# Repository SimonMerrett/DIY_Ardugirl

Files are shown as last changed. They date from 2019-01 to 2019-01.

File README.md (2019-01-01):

# DIY_Ardugirl
A SAMD21-based riff on the Arduboy handheld console. This is definitely Work in Progress and is not for production

The original has:
- ATmega32u4 processor 
- small OLED screen
- no additional storage
- speaker

This will have
- SAMD21G18A as it's processor
- larger daylight readable LCD screen, with dimmable backlight
- SPI flash and micro SD card slot (overkill - the latter may not be populated)
- headphone jack
- infrared rx/tx for possible multiplayer comms
- optional mini joystick

# Forum discussion
The Arduboy forum has [a thread](https://community.arduboy.com/t/wip-simon-merretts-arduboy-clone/6676) relevant to this design

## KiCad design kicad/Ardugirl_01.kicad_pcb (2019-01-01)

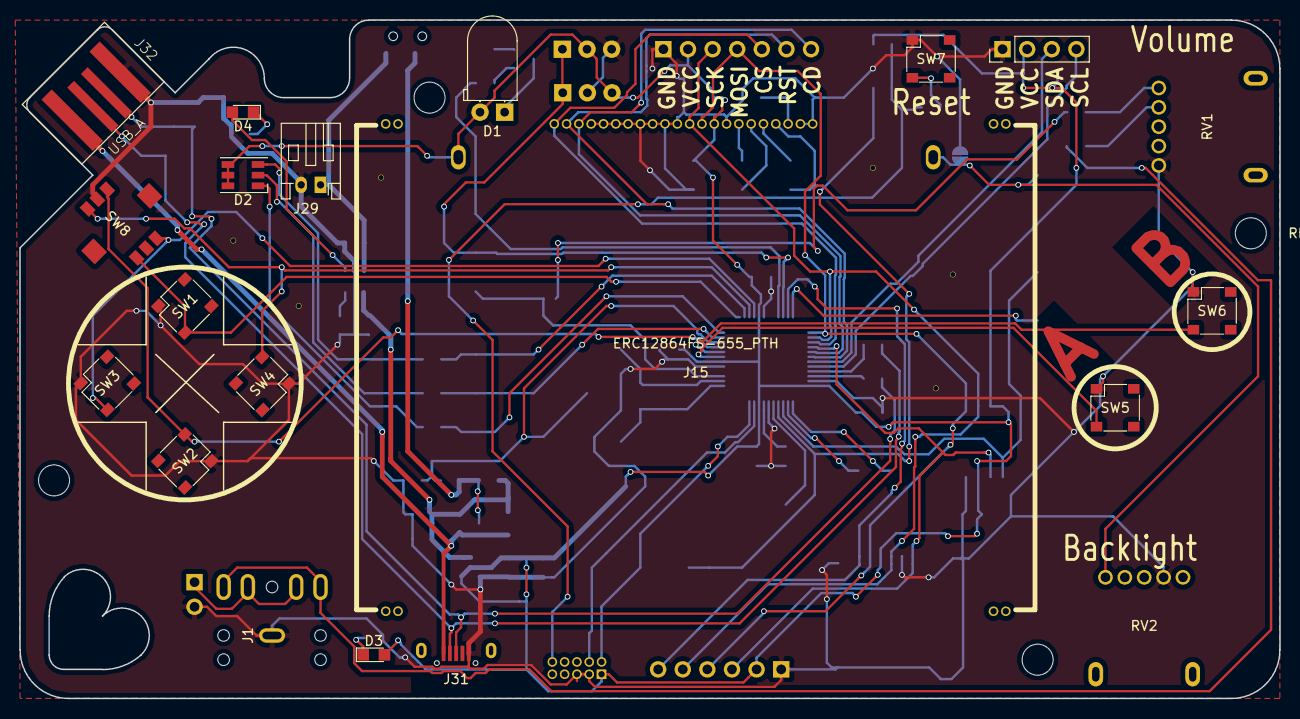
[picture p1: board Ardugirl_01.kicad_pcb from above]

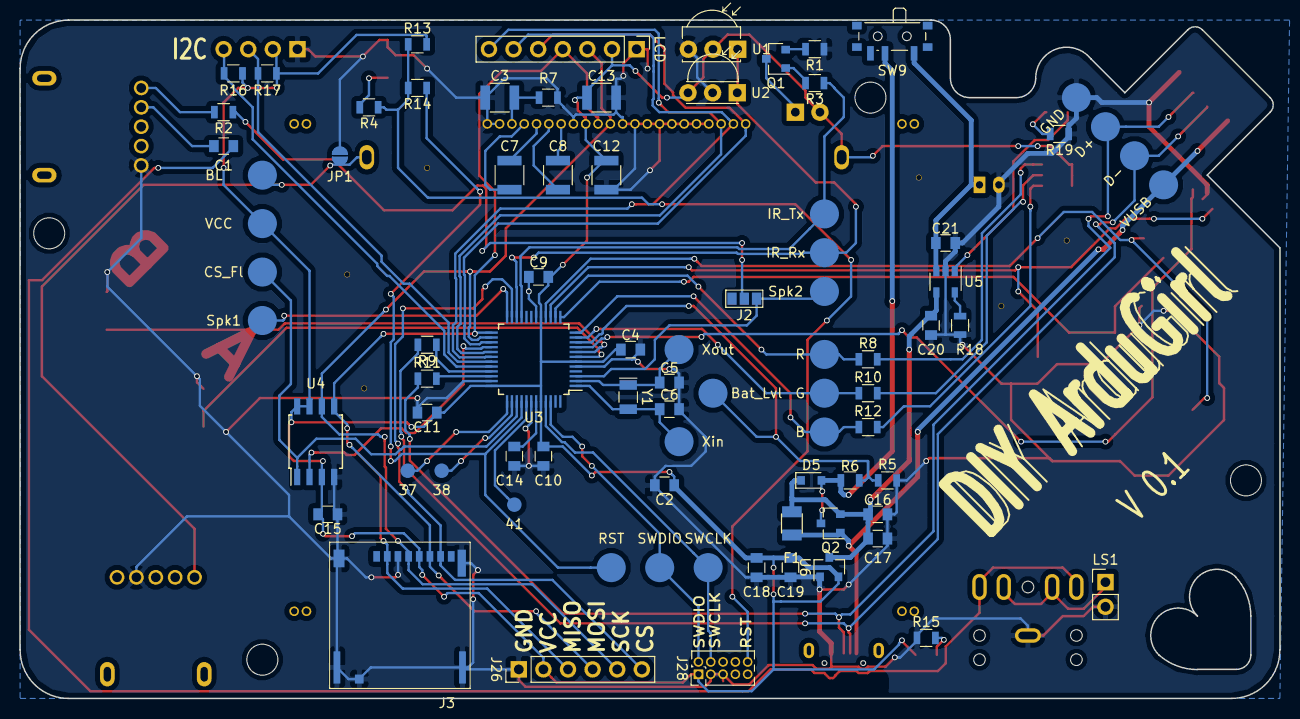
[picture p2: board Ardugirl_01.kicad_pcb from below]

Board: 2 copper layers, 130.0 x 70.0 mm, 102 parts (82 on the bottom side), 66 nets.

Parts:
37, 38: TP_Small; Measurement_Point_Round-SMD-Pad_Small
41: Measurement_Point_Round-SMD-Pad_Small
B: TEST; Measurement_Point_Round-SMD-Pad_Big
BL: K(-); Measurement_Point_Round-SMD-Pad_Big
Bat_Lvl: TEST; Measurement_Point_Round-SMD-Pad_Big
C1: 100u; C_0805
C2: 47u; C_0805
C3: 0.33u 25V; C_1210
C4, C9, C10, C11: 100n; C_0805
C5, C6: 12.5p; C_0805
C7, C8: 2.2u; C_1210
C12: 0.1u; C_1210
C13: 10u; C_1210
C14: C; C_0805
C15, C20, C21: 10u; C_0805
C16: Xu; C_0805
C17, C18: 1u; C_0805
C19: 0.1u; C_0805
CS_Fl: TEST; Measurement_Point_Round-SMD-Pad_Big
D1: IR_LED; LED_D5.0mm_Horizontal_O1.27mm_Z9.0mm
D2: LED_RGB; LED_RGB_PLCC-6
D3: PWR_LED; LED_0805
D4: LED; LED_0805
D5: D_Schottky; D_0805
D+: TEST; Measurement_Point_Round-SMD-Pad_Big
D-: TEST; Measurement_Point_Round-SMD-Pad_Big
F1: Polyfuse; Fuse_SMD1206_Reflow
G: TEST; Measurement_Point_Round-SMD-Pad_Big
GND: TEST_1P; Measurement_Point_Round-SMD-Pad_Big
I2C: I2C Header; Pin_Header_Straight_1x04_Pitch2.54mm
IR_Rx: TEST; Measurement_Point_Round-SMD-Pad_Big
IR_Tx: TEST; Measurement_Point_Round-SMD-Pad_Big
J1: JACK_TRS_5PINS; 3.5mm_Jack_5P
J2: GS3
J3: Micro_SD_Card; uSD_Molex
J15: CONN_01X24; ERC12864FS-655_PTH
J26: SD Header; Pin_Header_Straight_1x06_Pitch2.54mm
J28: SWD_02X05; Pin_Header_Straight_2x05_Pitch1.27mm
J29: CONN_BATT; JST_PH_S2B-PH-K_02x2.00mm_Angled
J31: USB_A; USB_micro-Korean_UF-M5DD-Y1
J32: USB_A; USB-A-PCB
JP1: Jumper_NO; JUMPER-SOLDER-SMD
LCD: LDC Header; Socket_Strip_Straight_1x07_Pitch2.54mm
LS1: Speaker; Pin_Header_Straight_1x02_Pitch2.54mm
Q1: Q_NMOS_GSD; SOT-23
Q2: Q_PMOS_GSD; SOT-23
R: TEST; Measurement_Point_Round-SMD-Pad_Big
R1: R; R_0805
R2: 270R; R_0805
R3, R9, R11: 22R; R_0805
R4: 47R; R_0805
R5, R6, R13, R16, R17: 10k; R_0805
R7: 10M; R_0805
R8, R10, R12, R15: 220R; R_0805
R14: 330R; R_0805
R18: 2k; R_0805
R19: 1k; R_0805
RST: TEST_1P; Measurement_Point_Round-SMD-Pad_Big
RV1: POT; Variable_R_PTH_5pin_14mm
RV2: 1k; Variable_R_PTH_5pin_14mm
SW1: UP; SW_Tactile_SMD_4.8_4.8
SW2: DOWN; SW_Tactile_SMD_4.8_4.8
SW3: LEFT; SW_Tactile_SMD_4.8_4.8
SW4: RIGHT; SW_Tactile_SMD_4.8_4.8
SW5: Button_A; SW_Tactile_SMD_4.8_4.8
SW6: Button_B; SW_Tactile_SMD_4.8_4.8
SW7: Reset; SW_Tactile_SMD_4.8_4.8
SW8: Joystick_5W; Joystick_5W_SKRH
SW9: SW_SPDT; SW_SPDT_PCM12
SWCLK: TEST; Measurement_Point_Round-SMD-Pad_Big
SWDIO: TEST; Measurement_Point_Round-SMD-Pad_Big
Spk1, Spk2: TEST; Measurement_Point_Round-SMD-Pad_Big
U1: TSOP325xx; IRReceiver_Vishay_MOLD-3pin
U2: TSOP335xx; IRReceiver_Vishay_MINIMOLD-3pin
U3: SAMD21G18A-MU; TQFP-48_7x7mm_Pitch0.5mm
U4: SST25PF040C; SOIJ-8_5.3x5.3mm_Pitch1.27mm
U5: MCP73831; SOT-23-5
U6: MCP1700T-3002E/TT; SOT-23
VCC: A(+); Measurement_Point_Round-SMD-Pad_Big
VUSB: TEST_1P; Measurement_Point_Round-SMD-Pad_Big
Xin: TEST; Measurement_Point_Round-SMD-Pad_Big
Xout: TEST; Measurement_Point_Round-SMD-Pad_Big
Y1: 32.768kHz; Crystal_SMD_G8-2pin_3.2x1.5mm

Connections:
/BL: BL.1, J15.24, JP1.1, RV2.3
/Batt_Level: Bat_Lvl.1, R5.1, R6.2, U3.10
/Button_A: SW5.2, U3.7
/Button_B: SW6.2, U3.8
/D+: D+.1, J31.3, J32.3, R11.1
/D-: D-.1, J31.2, J32.2, R9.2
/DOWN: SW2.2, SW8.4, U3.9
/Flash_CS: CS_Fl.1, U3.39, U4.1
/I2C_SCL: I2C.4, R16.1, U3.32
/I2C_SDA: I2C.3, R17.2, U3.31
/IR_Rx: IR_Rx.1, U1.1, U2.1, U3.22
/IR_Tx: IR_Tx.1, R3.1, U3.21
/LCD_CD: J15.3, LCD.7, U3.29
/LCD_CS: J15.1, LCD.5, U3.27
/LCD_RST: J15.2, LCD.6, U3.30
/LEFT: SW3.2, SW8.3, U3.16
/MISO: J3.7, J26.3, U3.28, U4.2
/MOSI: J3.3, J15.13, J26.4, LCD.4, U3.25, U4.5
/RESET: J28.10, R4.1, R13.1, R14.2
/RGB_Blue: B.1, R12.1, U3.12
/RGB_Green: G.1, R10.1, U3.11
/RGB_Red: R.1, R8.1, U3.14
/RIGHT: SW4.2, SW8.6, U3.15
/SCK: J3.5, J15.12, J26.5, LCD.3, U3.26, U4.6
/SD_CS: J3.2, J26.6, U3.23
/SWCLK: J28.4, SWCLK.1, U3.45
/SWDIO: J28.2, SWDIO.1, U3.46
/Sp+: J1.3, J1.4, LS1.1
/Speaker2: J2.3, Spk2.1, U3.3
/Speaker_1: Spk1.1, U3.24
/UP: SW1.2, SW8.1, U3.13
/VBAT: C21.1, J29.1, SW9.1, U5.3
/VCC: C2.1, C4.1, C9.2, C10.1, C11.1, C12.1, C13.1, C15.2, C18.1, C19.1, D1.2, D2.4, D2.5, D2.6, D3.2, I2C.2, J3.4, J15.14, J15.23, J26.2, J28.1, LCD.2, R13.2, R16.2, R17.1, U1.2, U2.3, U3.6, U3.17, U3.36, U3.44, U4.3, U4.7, U4.8, U6.2, VCC.1
/VIN: C16.1, C17.1, C20.1, D5.1, F1.1, Q2.2, U5.4, U6.3
/VSW: D5.2, Q2.3, R6.1, SW9.2
/VUSB: F1.2, J31.1, J32.1, Q2.1, VUSB.1
/Xtal_in: C6.1, U3.1, Xin.1, Y1.2
/Xtal_out: C5.1, U3.2, Xout.1, Y1.1
GND: C2.2, C3.1, C4.2, C5.2, C6.2, C9.1, C10.2, C11.2, C12.2, C13.2, C14.2, C15.1, C16.2, C17.2, C18.2, C19.2, C20.2, C21.2, GND.1, I2C.1, J1.1, J3.6, J3.9, J15.4, J15.5, J15.6, J15.7, J15.8, J15.9, J15.10, J15.11, J15.15, J15.21, J15.22, J26.1, J28.3, J28.5, J29.2, J31.4, J31.5, J32.4, JP1.2, LCD.1, LS1.2, R1.1, R5.2, R7.1, R15.1, R18.2, R19.1, RV1.3, RV2.2, SW1.1, SW2.1, SW3.1, SW4.1, SW5.1, SW6.1, SW7.1, SW8.5, U1.3, U2.2, U3.5, U3.18, U3.35, U3.42, U4.4, U5.2, U6.1
unnamed: C1.1, RV1.2
unnamed: C1.2, J1.2, J1.5
unnamed: C3.2, J15.20, R7.2
unnamed: C7.1, J15.19
unnamed: C7.2, J15.18
unnamed: C8.1, J15.17
unnamed: C8.2, J15.16
unnamed: C14.1, U3.43
unnamed: D1.1, Q1.3
unnamed: D2.1, R12.2
unnamed: D2.2, R10.2
unnamed: D2.3, R8.2
unnamed: D3.1, R15.2
unnamed: D4.1, R19.2
unnamed: D4.2, U5.1
unnamed: J2.2, R2.1
unnamed: R14.1, RST.1, U3.40
unnamed: Q1.1, R3.2
unnamed: Q1.2, R1.2
unnamed: R2.2, RV1.1
unnamed: R4.2, SW7.2
unnamed: R9.1, U3.33
unnamed: R11.2, U3.34
unnamed: R18.1, U5.5
unnamed: 37.1, U3.37
unnamed: 38.1, U3.38
unnamed: 41.1, U3.41
